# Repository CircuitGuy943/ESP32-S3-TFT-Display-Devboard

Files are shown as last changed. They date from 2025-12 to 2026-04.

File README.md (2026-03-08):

# ESP32 TFT Display Devboard

The ESP TFT Devboard is a devboard based on the ESP32-S3-WROOM-1 module with an integrated 40-pin connector designed to fully operate a TFT Display (one with a 3x8 RGB parallel interface) from the USB C connector only for power. It also has a bunch of breakout headers so that the GPIO pins can be accessed and used for other things, like a normal devboard whenever the display isn't being used. It consists of two USB C ports, one using the ESP32's built in USB connection and another using a USB to UART bridge (There is also a diode on each to ensure that the 5V doesn't backfeed if both USBs are connected). It then also consists of a boost converter to 24V for the LED Backlight and a current sink regulator to ensure it doesn't consume more than the rated current of 70mA.

## Features:
- Everything found on a normal devboard
- 2x USB C ports
- 24V, 5V and 3.3V outputs
- Support for a TFT 3x8 RGB display

## PCB
And this is my PCB. Very difficult to include everything in two layers but I managed to do it to save cost, and ommitted the use of an via in pads, the USB traces are length matched but the signals for the display don't need any trace/impedance matching as they don't run fast enough.

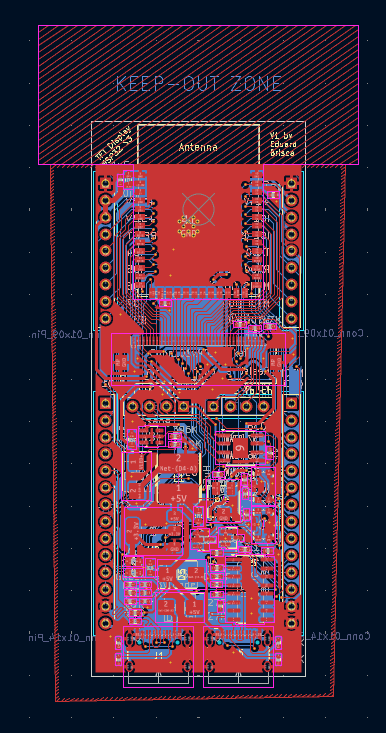
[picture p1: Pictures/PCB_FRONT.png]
PCB View
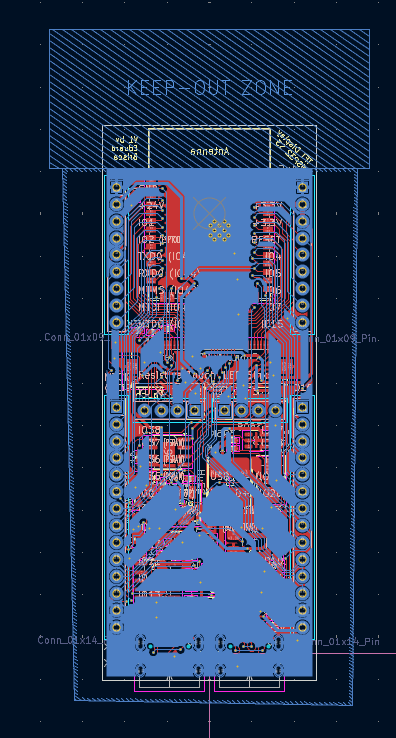
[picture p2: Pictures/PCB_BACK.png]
PCB Rendered View
  

And the Schematic:

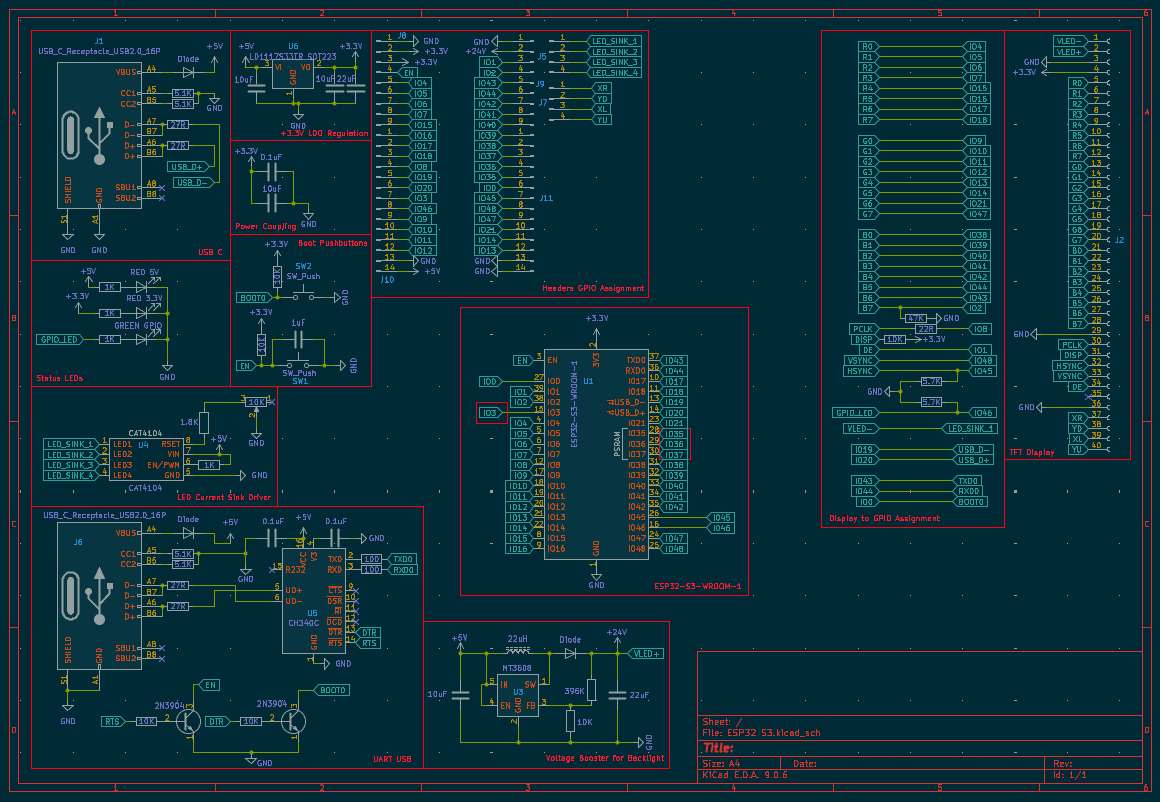
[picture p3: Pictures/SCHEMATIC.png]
Schematic


And here are some 3D views as well:

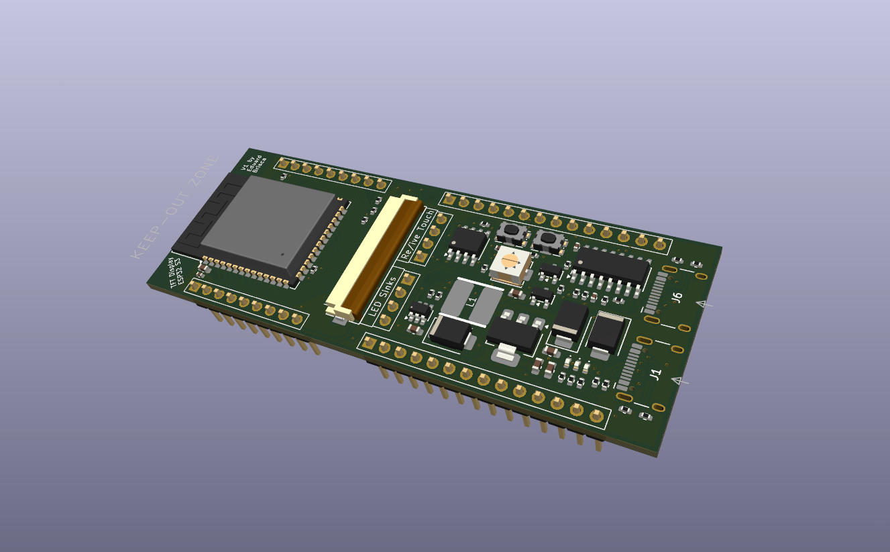
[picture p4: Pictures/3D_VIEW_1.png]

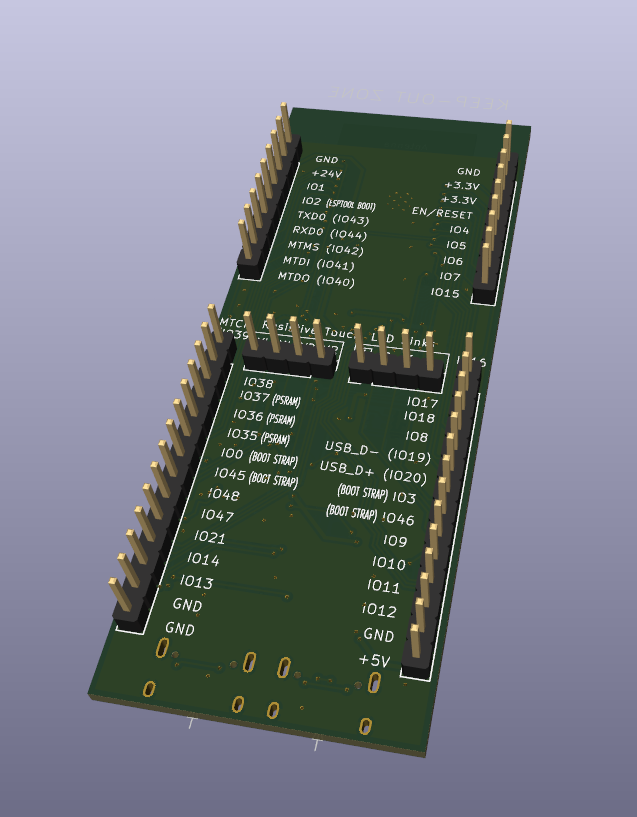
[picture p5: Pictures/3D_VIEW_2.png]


## Firmware Overview
I've included some basic firmware (**untested**) to get the TFT working but other than that it should function like a normal devboard hosting an ESP32

## BOM:
I have also included a .csv with the BOM list but here it is anyways.

 - 1x	CH340C	
 - 3x	Diode	
 - 2x	2N3904	
 - 2x	USB_C_Receptacle_USB2.0_16P	
 - 2x	5.7K	
 - 4x	5.1K	
 - 1x	47K	
 - 4x	1K	
 - 1x	1uF	
 - 3x	0.1uF
 - 4x	10uF
 - 6x	10K
 - 4x	27R
 - 1x	396K
 - 2x	100R
 - 1x	10K
 - 1x	MT3608
 - 1x	LD1117S33TR_SOT223
 - 1x	22R
 - 1x	ESP32-S3-WROOM-1
 - 2x	22uF
 - 1x	22uH
 - 2x	RED Led
 - 1x	GREEN Led
 - 2x	SW_Push
 - 1x	Conn_01x40_Socket
 - 1x	CAT4104
 - 1x	1.8K
 - 2x	Conn_01x14_Pin
 - 2x	Conn_01x04_Pin
 - 2x	Conn_01x09_Pin
(All parts for one devboard only)

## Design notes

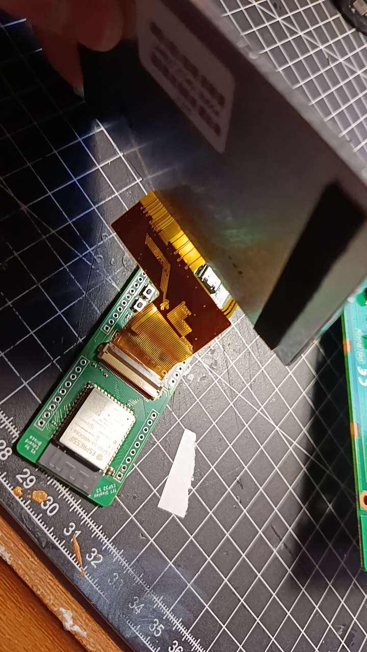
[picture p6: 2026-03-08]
Pictures/real1.jpg

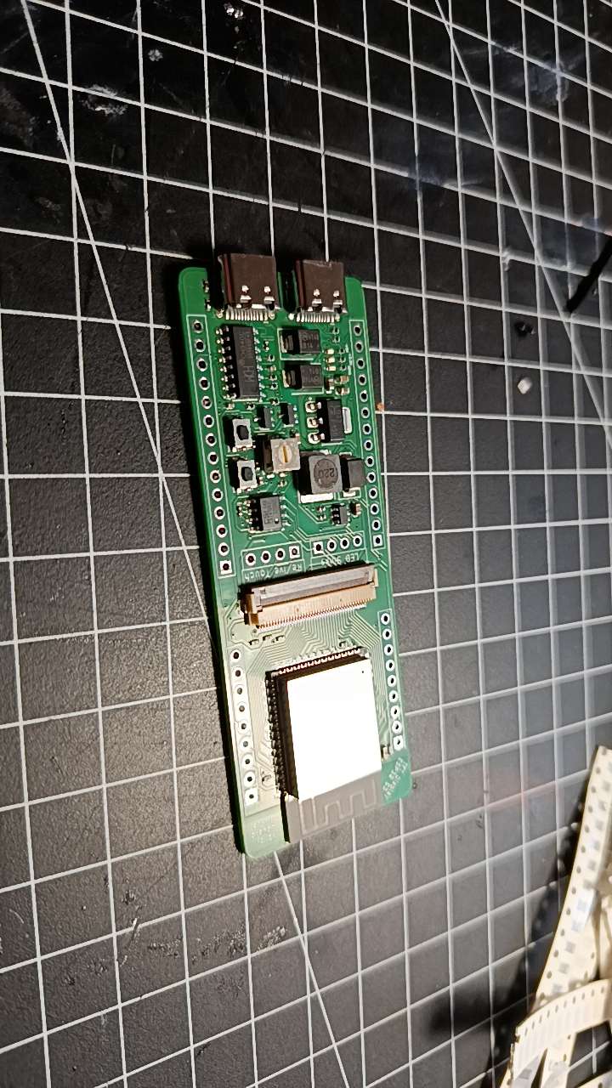
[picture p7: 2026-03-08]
Pictures/real3.jpg

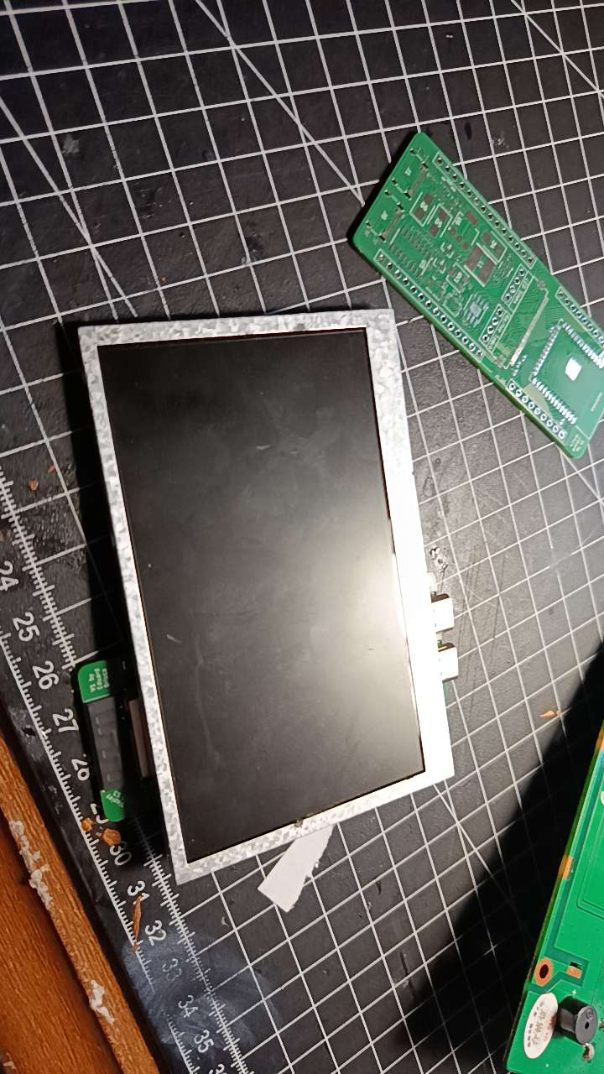
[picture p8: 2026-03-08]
Pictures/real4.jpg

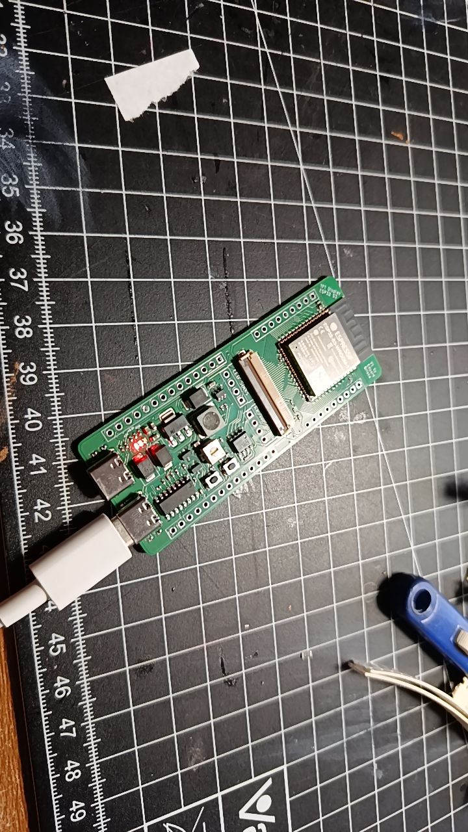
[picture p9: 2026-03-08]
Pictures/real5.jpg

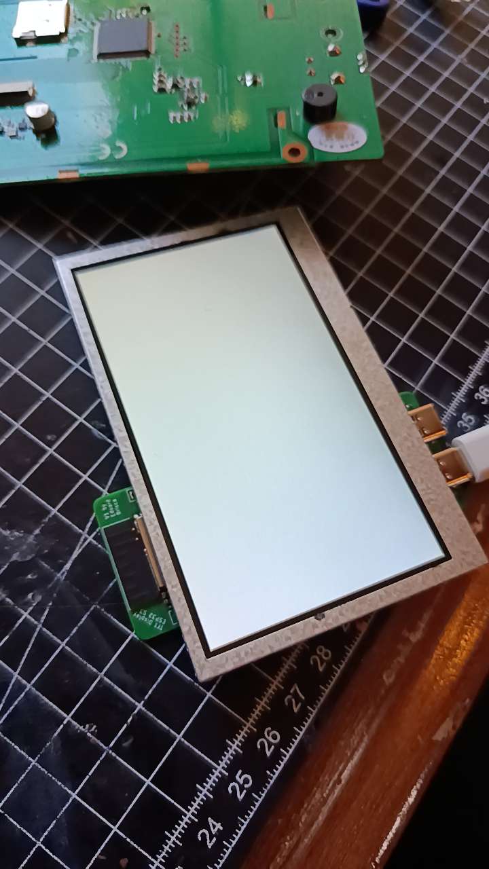
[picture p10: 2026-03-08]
Pictures/real2.jpg

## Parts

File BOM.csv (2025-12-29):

Quantity | Comment
1 | CH340C
3 | Diode
2 | 2N3904
2 | USB_C_Receptacle_USB2.0_16P
2 | 5.7K
4 | 5.1K
1 | 47K
4 | 1K
1 | 1uF
3 | 0.1uF
4 | 10uF
6 | 10K
4 | 27R
1 | 396K
2 | 100R
1 | 10K
1 | MT3608
1 | LD1117S33TR_SOT223
1 | 22R
1 | ESP32-S3-WROOM-1
2 | 22uF
1 | 22uH
1 | RED 3.3V
1 | RED 5V
1 | GREEN GPIO
2 | SW_Push
1 | Conn_01x40_Socket
1 | CAT4104
1 | 1.8K
2 | Conn_01x14_Pin
2 | Conn_01x04_Pin
2 | Conn_01x09_Pin | (All parts for one devboard only)
Total Component Price: | £17.85
PCB Price: | £2.37
Rest of PCBA | £59.41
Total | £79.63

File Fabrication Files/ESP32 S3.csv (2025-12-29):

Id | Designator | Footprint | Quantity | Comment | Supplier and ref | Column1 | _1
1 | U5 | SOIC-16_3.9x9.9mm_P1.27mm | 1 | CH340C
2 | D6,D4,D5 | D_SMB | 3 | Diode
3 | Q2,Q1 | SOT-23 | 2 | 2N3904
4 | J1,J6 | USB_C_Receptacle_HCTL_HC-TYPE-C-16P-01A | 2 | USB_C_Receptacle_USB2.0_16P
5 | R7,R17 | R_0402_1005Metric | 2 | 5.7K
6 | R22,R1,R2,R21 | R_0402_1005Metric | 4 | 5.1K
7 | R27 | R_0402_1005Metric | 1 | 47K
8 | R6,R12,R5,R14 | R_0402_1005Metric | 4 | 1K
9 | C10 | C_0402_1005Metric | 1 | 1uF
10 | C1,C7,C8 | C_0402_1005Metric | 3 | 0.1uF
11 | C3,C4,C6,C2 | C_0603_1608Metric | 4 | 10uF
12 | R26,R8,R25,R11,R9,R15 | R_0402_1005Metric | 6 | 10K
13 | R4,R20,R19,R3 | R_0402_1005Metric | 4 | 27R
14 | R10 | R_0402_1005Metric | 1 | 396K
15 | R23,R24 | R_0402_1005Metric | 2 | 100
16 | RV1 | Potentiometer_Bourns_3314J_Vertical | 1 | 10K
17 | U3 | SOT-23-6 | 1 | MT3608
18 | U6 | SOT-223-3_TabPin2 | 1 | LD1117S33TR_SOT223
19 | R18 | R_0402_1005Metric | 1 | 22R
20 | U1 | ESP32-S3-WROOM-1 | 1 | ESP32-S3-WROOM-1
21 | C5,C9 | C_0603_1608Metric | 2 | 22uF
22 | L1 | 5028_SMD_INDUCTOR_SRR5028-220Y | 1 | 22uH
23 | D2 | LED_0402_1005Metric | 1 | RED 3.3V
24 | D1 | LED_0402_1005Metric | 1 | RED 5V
25 | D3 | LED_0402_1005Metric | 1 | GREEN GPIO
26 | SW1,SW2 | SW_Push_1P1T-SH_NO_CK_KMR2xxG | 2 | SW_Push
27 | J2 | Hirose_FH12-40S-0.5SH_1x40-1MP_P0.50mm_Horizontal | 1 | Conn_01x40_Socket
28 | U4 | CAT4104 | 1 | CAT4104
29 | R13 | R_0402_1005Metric | 1 | 1.8K
30 | J11,J10 | PinHeader_1x14_P2.54mm_Vertical | 2 | Conn_01x14_Pin
31 | J5,J7 | PinHeader_1x04_P2.54mm_Vertical | 2 | Conn_01x04_Pin
32 | J8,J9 | PinHeader_1x09_P2.54mm_Vertical | 2 | Conn_01x09_Pin

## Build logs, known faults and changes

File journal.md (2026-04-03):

<!--
  This journal is auto generated by Hack Club Blueprint.
-->

# 1/6/2026 5:21 PM - Designed the first part of the schematic  

_Time spent: 3.0h_  

Did a bunch of researching on what exact ESP module I will need and setup the basic schematic for the dev board.

I decided to try and get modules with as much PSRAM as possible to allow easiest control of the TFT. The S3 variants provide the best performance and most PSRAM. The WROOM version will have to suffice for now, antenna is built in (not the U version) and it has the oscillator also built in. This means I don't need to worry about that part of the MCU control meaning there's less space for things to go wrong.

USB C also added, I had to figure out how USB exactly works and that it would need to run in 2.0 in my case. As it's USB C, there are also some other pins, CCs need to just be pulled down to as default for 5V power let through and I also needed to add series resistors on D+ and D- and only connect them to one set on the USB C because apparently USB C automatically selects the correct one depending on port orientation.

Since the ESP32s need 3.3V I also added an LDO (much cleaner than a buck converter), more specially the TO-252 package as that provides the most heat dissipation. This is important as the LDO burns excess voltage as heat and I would need to drop enough wattage for about 500-700mA to run the ESP, TFT and maybe other stuff, with capacitors as coupling as well on all rails and before and after the LDO. Plus LED's for the power rails and GPIO test LED like on most devboards.



# 1/6/2026 5:22 PM - Added backlight power for TFT display  

_Time spent: 3.0h_  

Added a button to the EN, almost forgot about it but it's needed to make sure the MCU actually runs and allows you to reset it. And also added another pushbutton on GPIO0 for bootstrapping (this needs to be pressed at the same time as reset to program the board).

And I came across quite a hurdle. I need 24V for the TFT backlight. Which is far from the 5V on the USB C. And I cannot just use an LDO. Best use would be a boost switching regulator such as the MT3608 to provide the 24V current. I found out the correct resistor feedback values for the VOUT and added the necessary inductor and other components such as coupling capacitors and diode. (I'm also trying to keep everything in SMD form). Using a Schottky diode as it's better for it's application because it's lower forward voltage and better switching performance.

Besides that I also need current limiting for the LED backlight array since the MT3608 only regulates voltage, not current. I could just use a current limiting resistor but that doesn't really work when the voltage is already at the one required by the LEDs so instead I need something more sophisticated. Therefore I found the CAT4104. It's in stock for JLCPCB however KiCad has no symbol/footprint for it so I had to figure out how make my own symbol and used a standard SOIC-8 footprint, making sure the pins are right (Hopefully JLCPCB will do PCBA for this). This IC basically is designed to drive some LED strips and limit current based on a ratio provided by a resistor. Which is perfect for my LED backlight.

I was going to add a logic MOSFET as well to PWM the backlight but the IC already has an EN pin capable of switching at PWM speeds so I can just connect that straight to a GPIO pin

(So far I have also made sure that all parts are in stock for PCBA by JLCPCB, although not all of them are Standard).



# 1/6/2026 5:23 PM - Assigning data lines  

_Time spent: 3.0h_  

I now need to assign the 24 RGB data lines and the other timing data lines to GPIO. I also need to take into consideration track length meaning I should probably have sequential pins. I also need to take into consideration this thing called DMA (which bypasses the CPU for writing pixels) and so I need to take into consideration the pins for this too.

To achieve all that I needed to: Assign normal RGB parallel and control pins to any GPIO almost (Except PSRAM, that is not to be touched, and any bootstrapping pins) and keep the RGB pins grouped for easy trace length matching and the resistive touchscreen pins need to be connected to ADC capable GPIOs so I attached them first.

(I also decided to separate the MCU, the connector AND the connection of pins between them (will make sense when you see it) just to make it much easier to visualize and to also make a breakout board for normal GPIO use (without display) much easier to setup.)

However upon doing this I realized I miscounted the pins quite a bit... Even with the main UART line (I don't need it for programming as I will use USB C) I only have about 27 free GPIO pins whereas just for the basic display, I need 29, an 4 extra for touch plus another 2 for built in LED and backlight PWM, putting me at 35, quite a bit over GPIO budget.

So I decided to forget about PWM control for the backlight and just add an SMD variable resistor and also remove the GPIO built-in LED that's seen on most boards, saving me 2 GPIOs and down to 33.

I can also use the 4 bootstrap pins. I still need to be careful though because they can mess up the boot sequence of the ESP32, however as long I just connect them to the resistive touch plate, they will still be floating and so won't push or pull a voltage over those pins at boot time, ensuring that the ESP32 can start fine. That's an extra 4 pins, bringing me to 31. (IO0, the bootstrap for normal/programming boot is pulled up currently but that will probably need to be done anyways to operate the resistive touchscreen)

There is also a pin called DISP on the display, this just enables whether the display is on or not and I can just pull this up permanently and have the display always on, I can tell it to display nothing from code. This brings me down to 32 needed GPIOs

However, very very annoyingly, I am still on GPIO pin short. So I will have to ditch the resistive touchscreen, any future projects needing a touchscreen will have to do without. That now leaves me with 28 needed GPIOs so I can re add the GPIO LED both on a bootstrap pin (obviously pulling it to ground as well to be safe). And leave IO0 untouched once more

OVERALL:

GPIO Needed:

x24 RGB Parallel Signal lines
x4 control lines (PCLK, HSYNC, VSYNC, DE)
x1 GPIO built-in LED
= x29

GPIO Available:

x27 normal GPIO available (x2 are default UART so they may need to be redefined in code?)
x2 bootstrap pins which can be used as long as there is a pull down and no other too strong pull ups (I've not also realized I must NOT touch IO3 as that needs to be left floating for proper boot as per the datasheet)
= x29

Now to go to bed and place all the nets in the best positions as per my first statement tomorrow, I will however make every pin accessible through breakout headers for flexibility in future projects.





# 1/6/2026 5:24 PM - Finished off the schematic, assigned nets, added UART USB  

_Time spent: 2.0h_  

I figured out which pins to use depending on their position on the physical package for ease of routing and assigned the nets for the GPIO Headers and the TFT display.

I also decided to make use of the UART with a UART to USB chip like most other S3 devboards do which I needed to find a UART to USB chip for and apparently there are output pins from the converter for EN and Boot strap pin 0? I don't understand exactly how a UART to USB bridge gives me that extra automation when programming the board with the UART USB and that isn't possible on the normal USB C but either way it's a plus if it works and if it does nothing then it's fine as the USB C normal port is there as well.

Then I also added the other LED sinks (including the TFT one) and the 4 resistive touchscreen pins to another 8 headers in case i ever want to use them in future or drive some heavier 24V LEDs (Although my current will be limited to 70mA or less).

This is where I am so far. Pretty much finished, I think, hopefully...



# 1/6/2026 5:27 PM - Had to tweak a few things on the schematic (possibly major)  

_Time spent: 1.0h_  

Did some more research and found out I had a plethora of problems.

First of all the two transistors on the bottom were wired wrong. Fixed that to make sure the inverting part of it actually worked.

Then it turns out the AMS1117 is not a good choice AT ALL (https://www.reddit.com/r/AskElectronics/comments/1nwdioi/whats_wrong_with_the_ams1117/) meaning I had to use something else like an LD1117 which is basically the same but avoids all of the problems mentioned in that reddit post.

Then I found out that GPIO2 is also used as a bootstrap by esptool so I added a weak pulldown to that and strengthened the ones on 45/46 just to be safe.

I also needed to add some extra capacitors here for power filtering and there including on the EN pin according to this: https://github.com/atomic14/basic-esp32s3-dev-board. The EN capacitor is VERY IMPORTANT because it creates an RC circuit that adds the necessary timing delay after power is applied (of about 50us minimum) for the power supply to stabilize, otherwise the ESP won't boot properly some of the time, which can be a problem, especially in things proper commercial products (this is still a devboard though but I don't want any unnecessary problems later on)

And the UART to USB isn't even needed because the EXACT same is present inside the chip package. But I will keep it anyways because it could be useful in future.



# 1/6/2026 5:28 PM - Found basic positions for components and grouped them.  

_Time spent: 3.0h_  

After a few attempts I found the best way to layout everything on the PCB would be the split the dual headers in two to make space for the 40-pin display connector. Because of how it's wired it would be easiest to have that 40-pin connector right opposite, and so the headers don't collide with the flexible PCB arm of the TFT display, it needs to be on the top layer. However I need to maintain a certain short distance between the two columns of headers so that it fits on a breadboard (The pitch is 2.54mm so all the headers had to be in those units basically, very annoying whoever created that 2.54). And because of that width restriction it collided with the 40-pin so I had to split the headers into 4 different rows.

In addition to that I also ensured the right headers were in the right place.

Then I started organizing the components by their specific purpose. I separated the LD1117 circuitry, moved power coupling for MCU up, LED's in one group, pushbuttons in one group, MT3608 in another group, CAT4104 as well plus the UART to USB chip and placed everything above it's relevant USB as well if it had one.

I dearly hope I will have enough space to route otherwise I'll have to get creative.

P.S. I also found out I need to have at least 0.4mm (I think) in-between Pads/components for JCLPCB to do PCBA.





# 1/6/2026 5:29 PM - Finished placing components in their best places  

_Time spent: 0.5h_  

I finished placing the components in their best (I think) positions for routing. I also left some clearance in front of the connector as I realize that it is very low. This means the flexible cable might collide with some of the taller components so I made sure to them back far enough. Most of the main components are in the correct places, the capacitors and resistors however may move depending on routing situation.

I plan to connect the MCU to the 40-pin with all the lines first on the top layer, they run vias into the inside of the MCU package cover and then run the MCU GPIO signals on the bottom layer to all the headers on the sides for general "devboarding". Then the rest of the components can use the top layer and maybe the bottom layer at a stretch. I hope that this will all fit in terms of traces and I won't have to extend/move and reroute.





# 1/6/2026 5:30 PM - Routed the first part of the PCB  

_Time spent: 1.5h_  

Routed the signal and GPIO lines for the TFT Display and the lines for the GPIO from the MCU to the header through the bottom layer while trying to leave as much space as possible for the rest of the power components lower down on the board.







# 1/6/2026 5:30 PM - Finished routing the PCB  

_Time spent: 2.5h_  

After a lot of trying attempts on the last few traces I FINALLY managed to complete routing the board. Completely surprised myself as I managed to do it while only keeping to two layers and no via-in-pads! I did however end up using about 6 vias on the last route but it's fine because it's just the EN signal, and if that is a few microseconds late then it will make no difference.

Hopefully all the measurements in-between the components are wide enough for JLCPCB's PCBA, I have checked and 0.4mm between components seems to be the minimum at the cheapest cost, and I've kept well more than 0.4mm.







# 1/6/2026 5:31 PM - Added Ground plane and fixed DRC errors  

_Time spent: 1.0h_  

Spent a good hour trying to figure out how to fix DRC errors and add the ground plane. I probably just about doubled the number of Vias on the board just to get all the ground planes connected very annoyingly, and had to nudge a few things to get both ground planes to work and for thermal relief to be alright.



# 1/6/2026 5:32 PM - Fixed a few more problems and added silkscreen. FINALLY DONE  

_Time spent: 1.0h_  

There were a few more things to fix in the schematic and upgrade. Plus I changed some of the net names for ease of reading. Then I finished the silkscreen on both sides. FINALLY. There is a complete list of all the pins labelling the headers (Plus bootstrap / PSRAM pin labelling for caution) and I cleaned up the silkscreen on the front of the board. I think I'm practically done with this for now. I have some sort of list in JLCPCB I just need to export BOM, ensure the list is complete then I'm ready to order it!





# 1/6/2026 5:32 PM - Banner image  

_Time spent: 0.1h_  



(Filler Filler Filler Filler Filler Filler Filler Filler Filler Filler Filler Filler Filler Filler Filler Filler Filler Filler Filler Filler Filler Filler

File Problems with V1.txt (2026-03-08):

24V bust converter is not layout correctly so it doesn't properly boost and messes with 5V rail which messes with ground and MCU. Ground plane is alos not good enough

Not all parallel RGB pins are needed for LovyanGFX if you don't want full color.

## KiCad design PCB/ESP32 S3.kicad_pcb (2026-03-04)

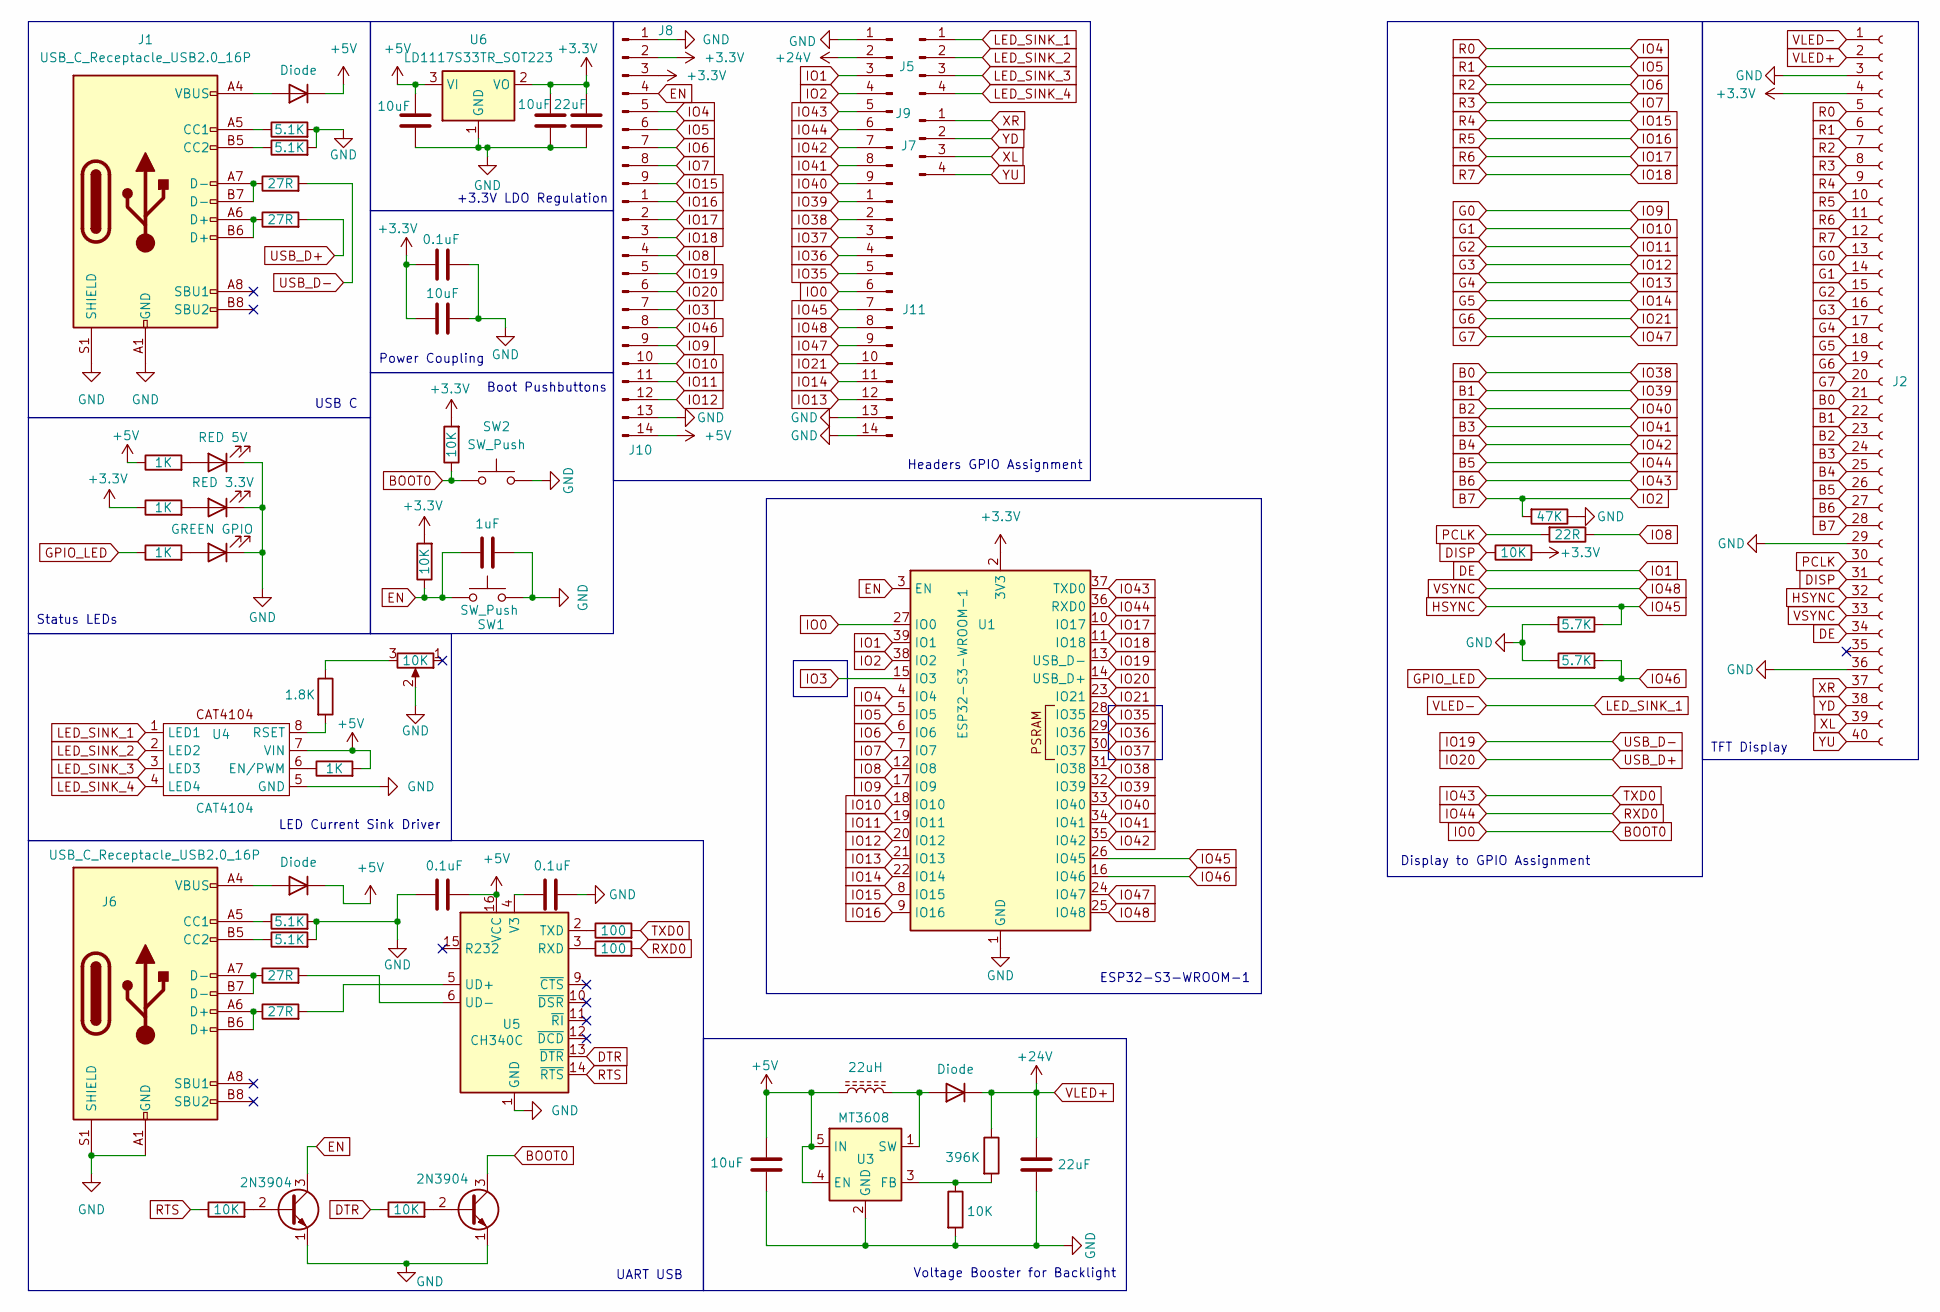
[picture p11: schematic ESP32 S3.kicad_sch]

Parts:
C1, C7, C8: 0.1uF; C_0402_1005Metric
C2, C3, C4, C6: 10uF; C_0603_1608Metric
C5, C9: 22uF; C_0603_1608Metric
C10: 1uF; C_0402_1005Metric
D1: RED 5V; LED_0402_1005Metric
D2: RED 3.3V; LED_0402_1005Metric
D3: GREEN GPIO; LED_0402_1005Metric
D4, D5, D6: Diode; D_SMB
J1, J6: USB_C_Receptacle_USB2.0_16P; USB_C_Receptacle_HCTL_HC-TYPE-C-16P-01A
J2: Conn_01x40_Socket; Hirose_FH12-40S-0.5SH_1x40-1MP_P0.50mm_Horizontal
J5, J7: Conn_01x04_Pin; PinHeader_1x04_P2.54mm_Vertical
J8, J9: Conn_01x09_Pin; PinHeader_1x09_P2.54mm_Vertical
J10, J11: Conn_01x14_Pin; PinHeader_1x14_P2.54mm_Vertical
L1: 22uH; 5028_SMD_INDUCTOR_SRR5028-220Y
Q1, Q2: 2N3904; SOT-23
R1, R2, R21, R22: 5.1K; R_0402_1005Metric
R3, R4, R19, R20: 27R; R_0402_1005Metric
R5, R6, R12, R14: 1K; R_0402_1005Metric
R7, R17: 5.7K; R_0402_1005Metric
R8, R9, R11, R15, R25, R26: 10K; R_0402_1005Metric
R10: 396K; R_0402_1005Metric
R13: 1.8K; R_0402_1005Metric
R18: 22R; R_0402_1005Metric
R23, R24: 100; R_0402_1005Metric
R27: 47K; R_0402_1005Metric
RV1: 10K; Potentiometer_Bourns_3314J_Vertical
SW1, SW2: SW_Push; SW_Push_1P1T-SH_NO_CK_KMR2xxG
U1: ESP32-S3-WROOM-1
U3: MT3608; SOT-23-6
U4: CAT4104
U5: CH340C; SOIC-16_3.9x9.9mm_P1.27mm
U6: LD1117S33TR_SOT223; SOT-223-3_TabPin2

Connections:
+3.3V: C1.2, C2.2, C4.2, C9.2, J2.4, J8.2, J8.3, R6.1, R8.2, R9.2, R15.2, U1.2 (3V3), U6.2 (VO)
+5V: C3.1, C6.2, C8.2, D5.1 (K), D6.1 (K), J10.14, L1.1, R5.1, R12.2, U3.4 (EN), U3.5 (IN), U4.7 (VIN), U5.16 (VCC), U6.3 (VI)
B0: J2.21, J11.2, U1.31 (IO38)
B1: J2.22, J11.1, U1.32 (IO39)
B2: J2.23, J9.9, U1.33 (IO40)
B3: J2.24, J9.8, U1.34 (IO41)
B4: J2.25, J9.7, U1.35 (IO42)
B5: J2.26, J9.6, R23.2, U1.36 (RXD0)
B6: J2.27, J9.5, R24.2, U1.37 (TXD0)
B7: J2.28, J9.4, R27.2, U1.38 (IO2)
BOOT0: J11.6, Q2.3 (C), R9.1, SW2.1, U1.27 (IO0)
DE: J2.34, J9.3, U1.39 (IO1)
DISP: J2.31, R15.1
DTR: R25.1, U5.13 (~DTR)
EN: C10.2, J8.4, Q1.3 (C), R8.1, SW1.1, U1.3 (EN)
G0: J2.13, J10.9, U1.17 (IO9)
G1: J2.14, J10.10, U1.18 (IO10)
G2: J2.15, J10.11, U1.19 (IO11)
G3: J2.16, J10.12, U1.20 (IO12)
G4: J2.17, J11.12, U1.21 (IO13)
G5: J2.18, J11.11, U1.22 (IO14)
G6: J2.19, J11.10, U1.23 (IO21)
G7: J2.20, J11.9, U1.24 (IO47)
GND: C1.1, C2.1, C3.2, C4.1, C5.1, C6.1, C7.2, C8.1, C9.1, C10.1, D1.1 (K), D2.1 (K), D3.1 (K), J1.A1 (GND), J1.A12 (GND), J1.B1 (GND), J1.B12 (GND), J1.S1 (SHIELD), J2.3, J2.29, J2.36, J2.MP, J6.A1 (GND), J6.A12 (GND), J6.B1 (GND), J6.B12 (GND), J6.S1 (SHIELD), J8.1, J9.1, J10.13, J11.13, J11.14, Q1.1 (E), Q2.1 (E), R1.2, R2.2, R7.1, R11.2, R17.2, R21.2, R22.2, R27.1, RV1.2, SW1.2, SW1.SH, SW2.2, SW2.SH, U1.1 (GND), U1.40 (GND), U1.41 (GND), U3.2 (GND), U4.5 (GND), U5.1 (GND), U6.1 (GND)
GPIO19: J10.5, R3.2, U1.13 (USB_D-)
GPIO20: J10.6, R4.2, U1.14 (USB_D+)
GPIO_LED: J10.8, R7.2, R14.1, U1.16 (IO46)
HSYNC: J2.32, J11.7, R17.1, U1.26 (IO45)
IO3: J10.7, U1.15 (IO3)
IO4: J2.5, J8.5, U1.4 (IO4)
IO5: J2.6, J8.6, U1.5 (IO5)
IO6: J2.7, J8.7, U1.6 (IO6)
IO7: J2.8, J8.8, U1.7 (IO7)
IO8: J10.4, R18.1, U1.12 (IO8)
IO15: J2.9, J8.9, U1.8 (IO15)
IO16: J2.10, J10.1, U1.9 (IO16)
IO17: J2.11, J10.2, U1.10 (IO17)
IO18: J2.12, J10.3, U1.11 (IO18)
IO35: J11.5, U1.28 (IO35)
IO36: J11.4, U1.29 (IO36)
IO37: J11.3, U1.30 (IO37)
IO48: J2.33, J11.8, U1.25 (IO48)
LED_SINK_1: J2.1, J5.1, U4.1 (LED1)
LED_SINK_2: J5.2, U4.2 (LED2)
LED_SINK_3: J5.3, U4.3 (LED3)
LED_SINK_4: J5.4, U4.4 (LED4)
unnamed: D1.2 (A), R5.2
unnamed: D2.2 (A), R6.2
unnamed: D3.2 (A), R14.2
unnamed: D4.2 (A), L1.2, U3.1 (SW)
unnamed: D5.2 (A), J6.A4 (VBUS), J6.A9 (VBUS), J6.B4 (VBUS), J6.B9 (VBUS)
unnamed: D6.2 (A), J1.A4 (VBUS), J1.A9 (VBUS), J1.B4 (VBUS), J1.B9 (VBUS)
unnamed: J1.A5 (CC1), R1.1
unnamed: J1.B5 (CC2), R2.1
unnamed: J1.A6 (D+), J1.B6 (D+), R4.1
unnamed: J1.A7 (D-), J1.B7 (D-), R3.1
unnamed: J6.A5 (CC1), R21.1
unnamed: J6.B5 (CC2), R22.1
unnamed: J6.A6 (D+), J6.B6 (D+), R20.1
unnamed: J6.A7 (D-), J6.B7 (D-), R19.1
unnamed: Q1.2 (B), R26.2
unnamed: Q2.2 (B), R25.2
unnamed: R13.1, RV1.3
unnamed: R10.2, R11.1, U3.3 (FB)
unnamed: R12.1, U4.6 (EN/PWM)
unnamed: R13.2, U4.8 (RSET)
unnamed: R23.1, U5.3 (RXD)
unnamed: R24.1, U5.2 (TXD)
unnamed: R20.2, U5.5 (UD+)
unnamed: R19.2, U5.6 (UD-)
unnamed: C7.1, U5.4 (V3)
PCLK: J2.30, R18.2
RTS: R26.1, U5.14 (~RTS)
VLED+: C5.2, D4.1 (K), J2.2, J9.2, R10.1
XL: J2.39, J7.3
XR: J2.37, J7.1
YD: J2.38, J7.2
YU: J2.40, J7.4

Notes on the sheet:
UART USB
USB C
Boot Pushbuttons
+3.3V LDO Regulation
Power Coupling
Status LEDs
LED Current Sink Driver
ESP32-S3-WROOM-1
TFT Display
Headers GPIO Assignment
Display to GPIO Assignment
Voltage Booster for Backlight

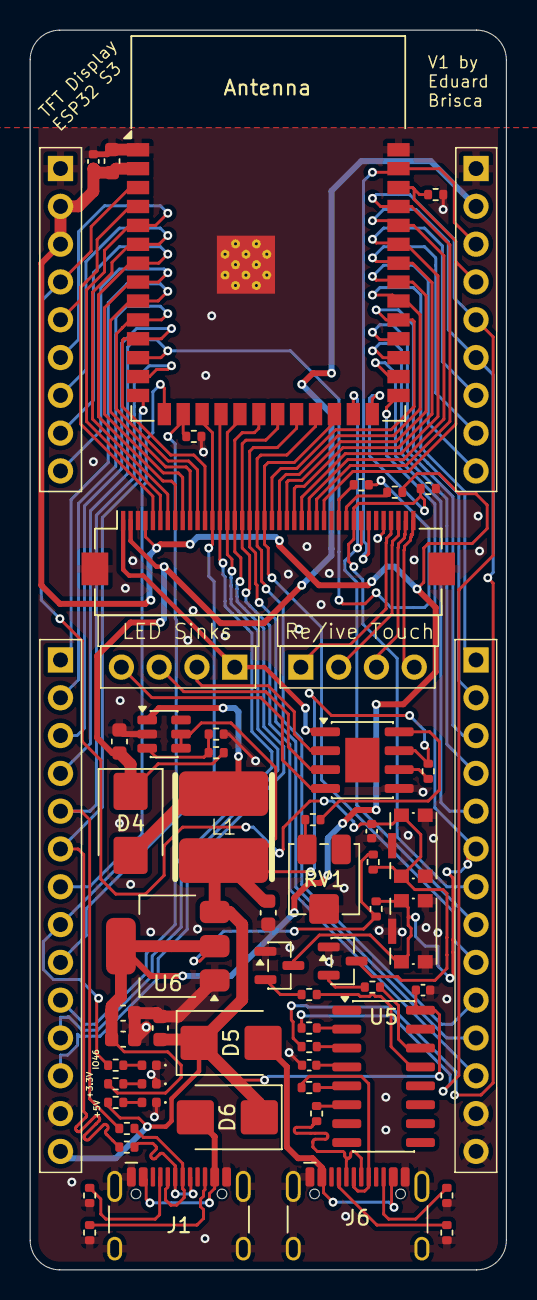
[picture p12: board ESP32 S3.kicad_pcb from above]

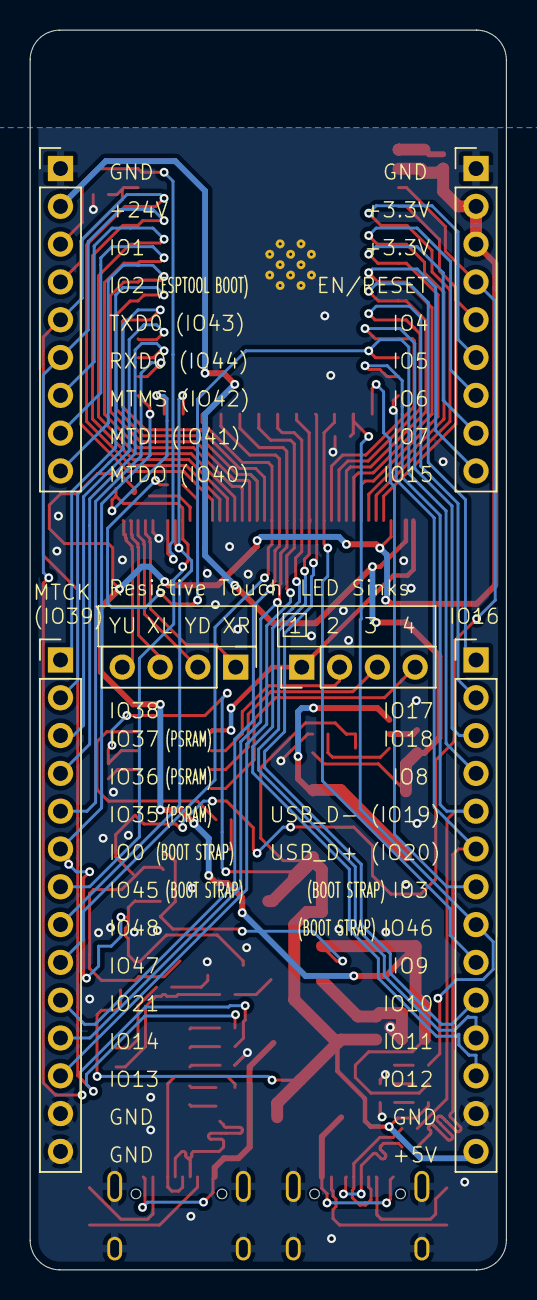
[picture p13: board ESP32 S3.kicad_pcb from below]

Board: 2 copper layers, 32.0 x 83.3 mm, 62 parts (6 on the bottom side), 78 nets.

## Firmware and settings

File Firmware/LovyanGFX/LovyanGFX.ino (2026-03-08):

#include <LovyanGFX.hpp>

// ESP32でLovyanGFXを独自設定で利用する場合の設定例

/// 独自の設定を行うクラスを、LGFX_Deviceから派生して作成します。
class LGFX : public lgfx::LGFX_Device
{
/*
 クラス名は"LGFX"から別の名前に変更しても構いません。
 AUTODETECTと併用する場合は"LGFX"は使用されているため、LGFX以外の名前に変更してください。
 また、複数枚のパネルを同時使用する場合もそれぞれに異なる名前を付けてください。
 ※ クラス名を変更する場合はコンストラクタの名前も併せて同じ名前に変更が必要です。

 名前の付け方は自由に決めて構いませんが、設定が増えた場合を想定し、
 例えばESP32 DevKit-CでSPI接続のILI9341の設定を行った場合、
  LGFX_DevKitC_SPI_ILI9341
 のような名前にし、ファイル名とクラス名を一致させておくことで、利用時に迷いにくくなります。
//*/


// 接続するパネルの型にあったインスタンスを用意します。
//lgfx::Panel_GC9A01      _panel_instance;
//lgfx::Panel_GDEW0154M09 _panel_instance;
//lgfx::Panel_HX8357B     _panel_instance;
//lgfx::Panel_HX8357D     _panel_instance;
//lgfx::Panel_ILI9163     _panel_instance;
  lgfx::Panel_ILI9341     _panel_instance;
//lgfx::Panel_ILI9342     _panel_instance;
//lgfx::Panel_ILI9481     _panel_instance;
//lgfx::Panel_ILI9486     _panel_instance;
//lgfx::Panel_ILI9488     _panel_instance;
//lgfx::Panel_IT8951      _panel_instance;
//lgfx::Panel_RA8875      _panel_instance;
//lgfx::Panel_SH110x      _panel_instance; // SH1106, SH1107
//lgfx::Panel_SSD1306     _panel_instance;
//lgfx::Panel_SSD1327     _panel_instance;
//lgfx::Panel_SSD1331     _panel_instance;
//lgfx::Panel_SSD1351     _panel_instance; // SSD1351, SSD1357
//lgfx::Panel_SSD1963     _panel_instance;
//lgfx::Panel_ST7735      _panel_instance;
//lgfx::Panel_ST7735S     _panel_instance;
//lgfx::Panel_ST7789      _panel_instance;
//lgfx::Panel_ST7796      _panel_instance;


// パネルを接続するバスの種類にあったインスタンスを用意します。
//lgfx::Bus_SPI        _bus_instance;   // SPIバスのインスタンス
//lgfx::Bus_I2C        _bus_instance;   // I2Cバスのインスタンス
lgfx::Bus_Parallel8  _bus_instance;   // 8ビットパラレルバスのインスタンス

// バックライト制御が可能な場合はインスタンスを用意します。(必要なければ削除)
//lgfx::Light_PWM     _light_instance;

// タッチスクリーンの型にあったインスタンスを用意します。(必要なければ削除)
//lgfx::Touch_CST816S          _touch_instance;
//lgfx::Touch_FT5x06           _touch_instance; // FT5206, FT5306, FT5406, FT6206, FT6236, FT6336, FT6436
//lgfx::Touch_GSL1680E_800x480 _touch_instance; // GSL_1680E, 1688E, 2681B, 2682B
//lgfx::Touch_GSL1680F_800x480 _touch_instance;
//lgfx::Touch_GSL1680F_480x272 _touch_instance;
//lgfx::Touch_GSLx680_320x320  _touch_instance;
//lgfx::Touch_GT911            _touch_instance;
//lgfx::Touch_STMPE610         _touch_instance;
//lgfx::Touch_TT21xxx          _touch_instance; // TT21100
//lgfx::Touch_XPT2046          _touch_instance;

public:

  // コンストラクタを作成し、ここで各種設定を行います。
  // クラス名を変更した場合はコンストラクタも同じ名前を指定してください。
  LGFX(void)
  {
    { // バス制御の設定を行います。
      auto cfg = _bus_instance.config();    // バス設定用の構造体を取得します。
/*
// SPIバスの設定
      cfg.spi_host = VSPI_HOST;     // 使用するSPIを選択  ESP32-S2,C3 : SPI2_HOST or SPI3_HOST / ESP32 : VSPI_HOST or HSPI_HOST
      // ※ ESP-IDFバージョンアップに伴い、VSPI_HOST , HSPI_HOSTの記述は非推奨になるため、エラーが出る場合は代わりにSPI2_HOST , SPI3_HOSTを使用してください。
      cfg.spi_mode = 0;             // SPI通信モードを設定 (0 ~ 3)
      cfg.freq_write = 40000000;    // 送信時のSPIクロック (最大80MHz, 80MHzを整数で割った値に丸められます)
      cfg.freq_read  = 16000000;    // 受信時のSPIクロック
      cfg.spi_3wire  = true;        // 受信をMOSIピンで行う場合はtrueを設定
      cfg.use_lock   = true;        // トランザクションロックを使用する場合はtrueを設定
      cfg.dma_channel = SPI_DMA_CH_AUTO; // 使用するDMAチャンネルを設定 (0=DMA不使用 / 1=1ch / 2=ch / SPI_DMA_CH_AUTO=自動設定)
      // ※ ESP-IDFバージョンアップに伴い、DMAチャンネルはSPI_DMA_CH_AUTO(自動設定)が推奨になりました。1ch,2chの指定は非推奨になります。
      cfg.pin_sclk = 18;            // SPIのSCLKピン番号を設定
      cfg.pin_mosi = 23;            // SPIのMOSIピン番号を設定
      cfg.pin_miso = 19;            // SPIのMISOピン番号を設定 (-1 = disable)
      cfg.pin_dc   = 27;            // SPIのD/Cピン番号を設定  (-1 = disable)
     // SDカードと共通のSPIバスを使う場合、MISOは省略せず必ず設定してください。
//*/
/*
// I2Cバスの設定
      cfg.i2c_port    = 0;          // 使用するI2Cポートを選択 (0 or 1)
      cfg.freq_write  = 400000;     // 送信時のクロック
      cfg.freq_read   = 400000;     // 受信時のクロック
      cfg.pin_sda     = 21;         // SDAを接続しているピン番号
      cfg.pin_scl     = 22;         // SCLを接続しているピン番号
      cfg.i2c_addr    = 0x3C;       // I2Cデバイスのアドレス
//*/

// 8ビットパラレルバスの設定
      cfg.i2s_port = I2S_NUM_0;     // 使用するI2Sポートを選択 (I2S_NUM_0 or I2S_NUM_1) (ESP32のI2S LCDモードを使用します)
      cfg.freq_write = 20000000;    // 送信クロック (最大20MHz, 80MHzを整数で割った値に丸められます)
      cfg.pin_wr =  4;              // WR を接続しているピン番号
      cfg.pin_rd =  2;              // RD を接続しているピン番号
      cfg.pin_rs = 15;              // RS(D/C)を接続しているピン番号
      cfg.pin_d0 = 12;              // D0を接続しているピン番号
      cfg.pin_d1 = 13;              // D1を接続しているピン番号
      cfg.pin_d2 = 26;              // D2を接続しているピン番号
      cfg.pin_d3 = 25;              // D3を接続しているピン番号
      cfg.pin_d4 = 17;              // D4を接続しているピン番号
      cfg.pin_d5 = 16;              // D5を接続しているピン番号
      cfg.pin_d6 = 27;              // D6を接続しているピン番号
      cfg.pin_d7 = 14;              // D7を接続しているピン番号
//*/

      _bus_instance.config(cfg);    // 設定値をバスに反映します。
      _panel_instance.setBus(&_bus_instance);      // バスをパネルにセットします。
    }

    { // 表示パネル制御の設定を行います。
      auto cfg = _panel_instance.config();    // 表示パネル設定用の構造体を取得します。

      cfg.pin_cs           =    14;  // CSが接続されているピン番号   (-1 = disable)
      cfg.pin_rst          =    33;  // RSTが接続されているピン番号  (-1 = disable)
      cfg.pin_busy         =    -1;  // BUSYが接続されているピン番号 (-1 = disable)

      // ※ 以下の設定値はパネル毎に一般的な初期値が設定されていますので、不明な項目はコメントアウトして試してみてください。

      cfg.panel_width      =   240;  // 実際に表示可能な幅
      cfg.panel_height     =   320;  // 実際に表示可能な高さ
      cfg.offset_x         =     0;  // パネルのX方向オフセット量
      cfg.offset_y         =     0;  // パネルのY方向オフセット量
      cfg.offset_rotation  =     0;  // 回転方向の値のオフセット 0~7 (4~7は上下反転)
      cfg.dummy_read_pixel =     8;  // ピクセル読出し前のダミーリードのビット数
      cfg.dummy_read_bits  =     1;  // ピクセル以外のデータ読出し前のダミーリードのビット数
      cfg.readable         =  true;  // データ読出しが可能な場合 trueに設定
      cfg.invert           = false;  // パネルの明暗が反転してしまう場合 trueに設定
      cfg.rgb_order        = false;  // パネルの赤と青が入れ替わってしまう場合 trueに設定
      cfg.dlen_16bit       = false;  // 16bitパラレルやSPIでデータ長を16bit単位で送信するパネルの場合 trueに設定
      cfg.bus_shared       =  true;  // SDカードとバスを共有している場合 trueに設定(drawJpgFile等でバス制御を行います)

// 以下はST7735やILI9163のようにピクセル数が可変のドライバで表示がずれる場合にのみ設定してください。
//    cfg.memory_width     =   240;  // ドライバICがサポートしている最大の幅
//    cfg.memory_height    =   320;  // ドライバICがサポートしている最大の高さ

      _panel_instance.config(cfg);
    }

//*
    { // バックライト制御の設定を行います。（必要なければ削除）
      auto cfg = _light_instance.config();    // バックライト設定用の構造体を取得します。

      cfg.pin_bl = 32;              // バックライトが接続されているピン番号
      cfg.invert = false;           // バックライトの輝度を反転させる場合 true
      cfg.freq   = 44100;           // バックライトのPWM周波数
      cfg.pwm_channel = 7;          // 使用するPWMのチャンネル番号

      _light_instance.config(cfg);
      _panel_instance.setLight(&_light_instance);  // バックライトをパネルにセットします。
    }
//*/

//*
    { // タッチスクリーン制御の設定を行います。（必要なければ削除）
      auto cfg = _touch_instance.config();

      cfg.x_min      = 0;    // タッチスクリーンから得られる最小のX値(生の値)
      cfg.x_max      = 239;  // タッチスクリーンから得られる最大のX値(生の値)
      cfg.y_min      = 0;    // タッチスクリーンから得られる最小のY値(生の値)
      cfg.y_max      = 319;  // タッチスクリーンから得られる最大のY値(生の値)
      cfg.pin_int    = 38;   // INTが接続されているピン番号
      cfg.bus_shared = true; // 画面と共通のバスを使用している場合 trueを設定
      cfg.offset_rotation = 0;// 表示とタッチの向きのが一致しない場合の調整 0~7の値で設定

// SPI接続の場合
      cfg.spi_host = VSPI_HOST;// 使用するSPIを選択 (HSPI_HOST or VSPI_HOST)
      cfg.freq = 1000000;     // SPIクロックを設定
      cfg.pin_sclk = 18;     // SCLKが接続されているピン番号
      cfg.pin_mosi = 23;     // MOSIが接続されているピン番号
      cfg.pin_miso = 19;     // MISOが接続されているピン番号
      cfg.pin_cs   =  5;     //   CSが接続されているピン番号

// I2C接続の場合
      cfg.i2c_port = 1;      // 使用するI2Cを選択 (0 or 1)
      cfg.i2c_addr = 0x38;   // I2Cデバイスアドレス番号
      cfg.pin_sda  = 23;     // SDAが接続されているピン番号
      cfg.pin_scl  = 32;     // SCLが接続されているピン番号
      cfg.freq = 400000;     // I2Cクロックを設定

      _touch_instance.config(cfg);
      _panel_instance.setTouch(&_touch_instance);  // タッチスクリーンをパネルにセットします。
    }
//*/

    setPanel(&_panel_instance); // 使用するパネルをセットします。
  }
};

// 準備したクラスのインスタンスを作成します。
LGFX display;

void setup(void)
{
  // SPIバスとパネルの初期化を実行すると使用可能になります。
  display.init();

  display.setTextSize((std::max(display.width(), display.height()) + 255) >> 8);

  // タッチが使用可能な場合のキャリブレーションを行います。（省略可）
  if (display.touch())
  {
    if (display.width() < display.height()) display.setRotation(display.getRotation() ^ 1);

    // 画面に案内文章を描画します。
    display.setTextDatum(textdatum_t::middle_center);
    display.drawString("touch the arrow marker.", display.width()>>1, display.height() >> 1);
    display.setTextDatum(textdatum_t::top_left);

    // タッチを使用する場合、キャリブレーションを行います。画面の四隅に表示される矢印の先端を順にタッチしてください。
    std::uint16_t fg = TFT_WHITE;
    std::uint16_t bg = TFT_BLACK;
    if (display.isEPD()) std::swap(fg, bg);
    display.calibrateTouch(nullptr, fg, bg, std::max(display.width(), display.height()) >> 3);
  }

  display.fillScreen(TFT_BLACK);
}

uint32_t count = ~0;
void loop(void)
{
  display.startWrite();
  display.setRotation(++count & 7);
  display.setColorDepth((count & 8) ? 16 : 24);

  display.setTextColor(TFT_WHITE);
  display.drawNumber(display.getRotation(), 16, 0);

  display.setTextColor(0xFF0000U);
  display.drawString("R", 30, 16);
  display.setTextColor(0x00FF00U);
  display.drawString("G", 40, 16);
  display.setTextColor(0x0000FFU);
  display.drawString("B", 50, 16);

  display.drawRect(30,30,display.width()-60,display.height()-60,count*7);
  display.drawFastHLine(0, 0, 10);

  display.endWrite();

  int32_t x, y;
  if (display.getTouch(&x, &y)) {
    display.fillRect(x-2, y-2, 5, 5, count*7);
  }
}

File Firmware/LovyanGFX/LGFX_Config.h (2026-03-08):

#pragma once
#include <LovyanGFX.hpp>

class LGFX : public lgfx::LGFX_Device
{
  lgfx::Panel_Device* _panel;  // panel pointer

public:

  LGFX(void)
  {
    /* Allocate the panel dynamically */
    auto panel = new lgfx::Panel_RGB();
    
    auto cfg = panel->config();

    // Pixel clock & control pins
    cfg.pin_pclk = 8;
    cfg.pin_hsync = 45;
    cfg.pin_vsync = 48;
    cfg.pin_de    = 1;
    cfg.pin_rst   = -1;

    // RGB data pins (your pinout)
    cfg.pin_d0  = 38;  // B0
    cfg.pin_d1  = 39;  // B1
    cfg.pin_d2  = 40;  // B2
    cfg.pin_d3  = 41;  // B3
    cfg.pin_d4  = 42;  // B4

    cfg.pin_d5  = 9;   // G0
    cfg.pin_d6  = 10;  // G1
    cfg.pin_d7  = 11;  // G2
    cfg.pin_d8  = 12;  // G3
    cfg.pin_d9  = 13;  // G4
    cfg.pin_d10 = 14;  // G5

    cfg.pin_d11 = 4;  // R0
    cfg.pin_d12 = 5;  // R1
    cfg.pin_d13 = 6;  // R2
    cfg.pin_d14 = 7;  // R3
    cfg.pin_d15 = 15; // R4

    // Timing defaults
    cfg.hsync_pulse_width = 10;
    cfg.hsync_back_porch  = 20;
    cfg.hsync_front_porch = 10;
    cfg.vsync_pulse_width = 10;
    cfg.vsync_back_porch  = 10;
    cfg.vsync_front_porch = 10;

    cfg.freq_write = 12000000;  // pixel clock frequency

    cfg.rgb_order = false;
    cfg.invert = false;

    panel->config(cfg);

    _panel = panel;

    setPanel(_panel);  // set panel for LGFX_Device
  }
};

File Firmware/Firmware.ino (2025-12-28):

#include <ESP_Panel_Library.h>

// Create panel instance
ESP_Panel *panel = nullptr;

void setup() {
  Serial.begin(115200);
  delay(100);

  // Create panel object
  panel = new ESP_Panel();

  // Initialize and begin
  panel->init();
  panel->begin();

  // Wait a little
  delay(100);

  // Fill screen (RGB888 fill)
  panel->getLcd()->fillScreen(0xFF0000); // Red fill

  delay(1000);

  // Draw some simple text
  panel->getLcd()->drawString(10, 20, "Hello RGB Display",
                              /*color*/ 0x00FF00, /*bg*/ 0x000000);

  Serial.println("Display initialized");
}

void loop() {
  // Rotate/demo loop
  static uint32_t last = millis();
  if (millis() - last > 1000) {
    last = millis();
    // Cycle fill pattern
    static int state = 0;
    uint32_t color;
    if (state == 0) color = 0x0000FF; // Blue
    else if (state == 1) color = 0x00FF00; // Green
    else color = 0xFF0000; // Red

    panel->getLcd()->fillScreen(color);
    state = (state + 1) % 3;
  }
}

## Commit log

2025-12-30 Update with a few improvments
    [ESP32 S3.kicad_pcb]
2026-03-08 Add pictures and problem txt
    [LGFX_Config.h, LovyanGFX.ino]
